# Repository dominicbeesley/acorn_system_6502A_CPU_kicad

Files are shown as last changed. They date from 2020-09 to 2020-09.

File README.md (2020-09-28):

# acorn_system_6502A_CPU_kicad
 Acorn System 6502A clone card

 This is a clone of the Acorn 6502A 1/2/3 MHz card for the System Microcomputer range.

 It is not a perfect copy:
 - some routing (especially on the front copper plane) is not a perfect copy
 - some "extra wiggles" on the Acorn card have not been copied
 - some fixes have been added (see below)

It is intended that as it stands this is a drop-in replacement for the original card. If the fix jumpers are left alone then it should function identically.

# Fixes

Two extra decoupling capacitors and some extra routing has been added. C10 is added close to the CPU. Another C11 is close to IC12, for this to be effective an extra wire may need to be added on the underside of the board to connect VCC direct to the capacitor. It is not clear whether either of these are necessary but some pictures show an extra capacitor tacked onto IC12.

## CPU card always to Generate data stobes

On the original card the NRDS and NWDS data strobe signals are not always generated by the CPU card but are set to tri-state when the bus is granted to another card. This would require any DMA card to contains identical circuitry to the CPU card. An optional link LKD1 can be cut and re-made to have the CPU card always generate these signals.

## Data buffer direction on bus grant

There is seemingly a bug in the original card in that the direction is not reversed when the bus is granted and local (to the CPU card) resources are being accessed by another bus master. (The buffer enable signal _is_ however correctly reversed)

LKD2 if broken and remade will enable the buffer direction to be reversed. This should allow local resources (ROM, 6116, VIA) to be accessed by alternative bus masters.

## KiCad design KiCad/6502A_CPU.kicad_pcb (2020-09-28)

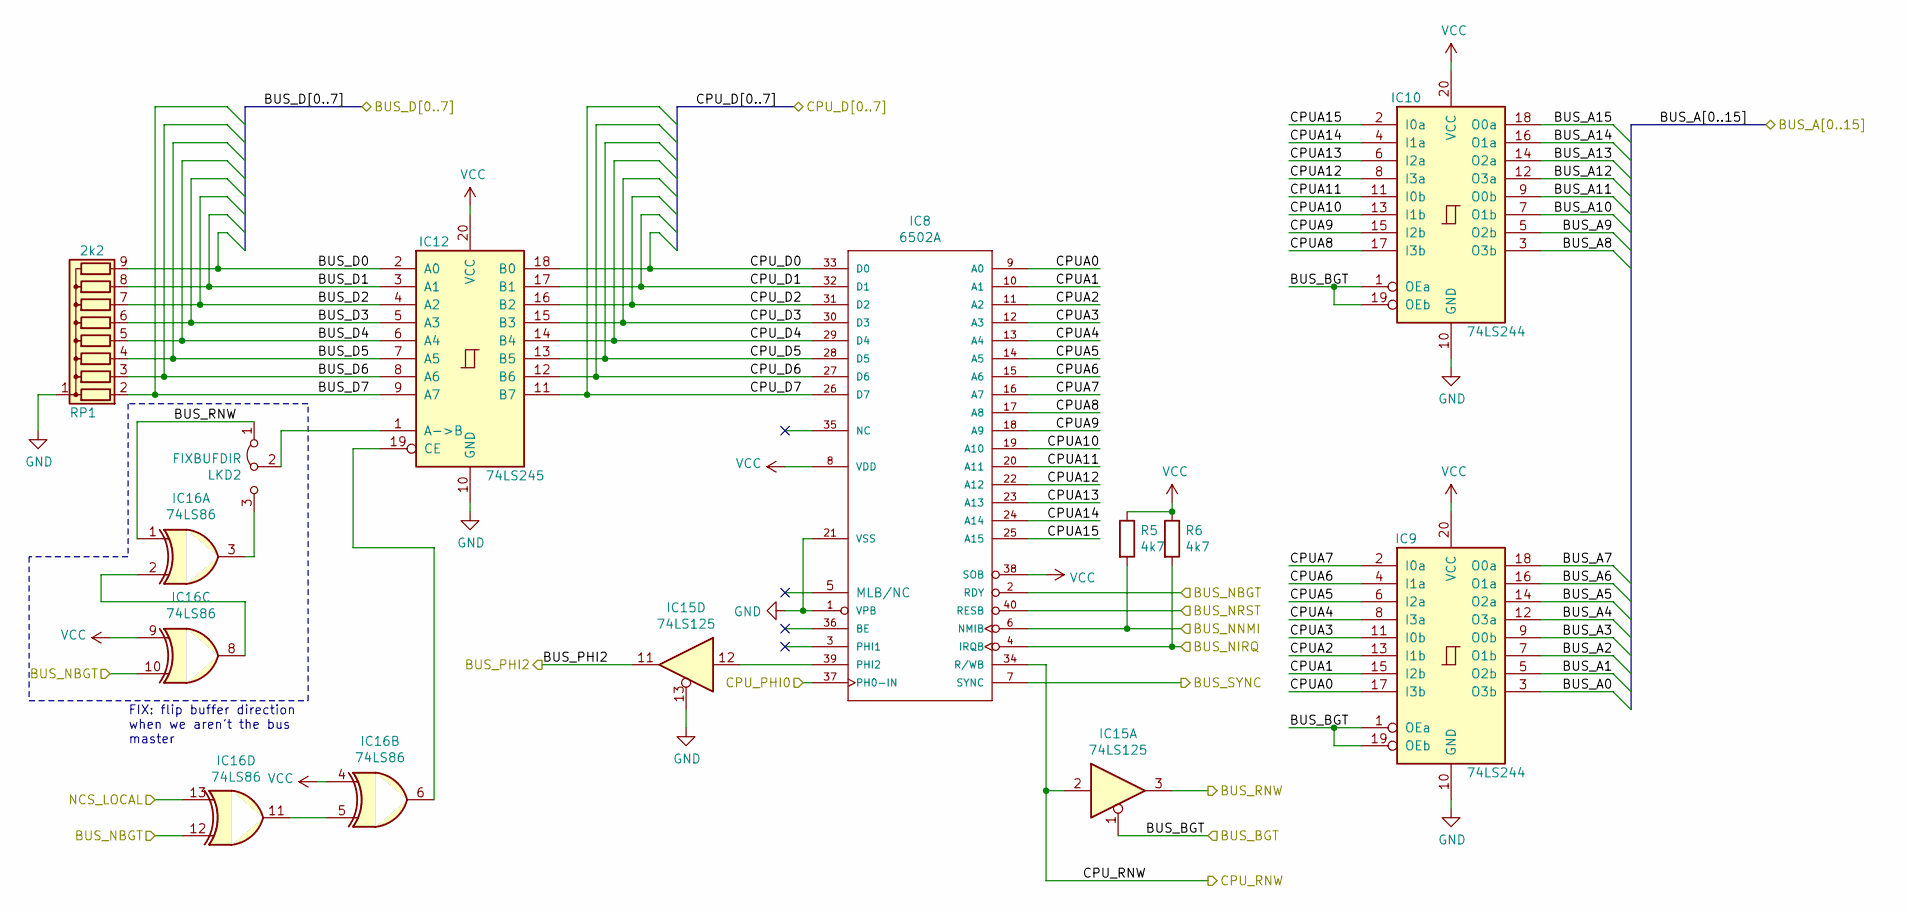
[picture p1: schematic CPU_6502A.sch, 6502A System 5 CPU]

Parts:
IC8: 6502A; DIP-40_W15.24mm_Socket
IC9, IC10: 74LS244; DIP-20_W7.62mm_Socket
IC12: 74LS245; DIP-20_W7.62mm_Socket
IC15: 74LS125; DIP-14_W7.62mm_Socket
IC16: 74LS86; DIP-14_W7.62mm_Socket
LKD2: FIXBUFDIR; Pin_Header_Straight_1x03_Pitch2.54mm_tight_NC12
R5, R6: 4k7; R_Axial_DIN0309_L9.0mm_D2.0mm_P12.70mm_Horizontal
RP1: 2k2; R_Array_SIP9

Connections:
/BUS_NBGT: IC8.2 (RDY), IC16.10, IC16.12; also elsewhere on the board
/BUS_NIRQ: IC8.4 (IRQB), R6.2; also elsewhere on the board
/BUS_NNMI: IC8.6 (NMIB), R5.2; also elsewhere on the board
/BUS_NRST: IC8.40 (RESB); also elsewhere on the board
/BUS_PHI2: IC15.11; also elsewhere on the board
/BUS_RNW: IC15.3, IC16.1, LKD2.1 (A); also elsewhere on the board
/BUS_SYNC: IC8.7 (SYNC); also elsewhere on the board
/CPU_6502A/BUS_A0: IC9.3 (O3b); also elsewhere on the board
/CPU_6502A/BUS_A1: IC9.5 (O2b); also elsewhere on the board
/CPU_6502A/BUS_A2: IC9.7 (O1b); also elsewhere on the board
/CPU_6502A/BUS_A3: IC9.9 (O0b); also elsewhere on the board
/CPU_6502A/BUS_A4: IC9.12 (O3a); also elsewhere on the board
/CPU_6502A/BUS_A5: IC9.14 (O2a); also elsewhere on the board
/CPU_6502A/BUS_A6: IC9.16 (O1a); also elsewhere on the board
/CPU_6502A/BUS_A7: IC9.18 (O0a); also elsewhere on the board
/CPU_6502A/BUS_A8: IC10.3 (O3b); also elsewhere on the board
/CPU_6502A/BUS_A9: IC10.5 (O2b); also elsewhere on the board
/CPU_6502A/BUS_A10: IC10.7 (O1b); also elsewhere on the board
/CPU_6502A/BUS_A11: IC10.9 (O0b); also elsewhere on the board
/CPU_6502A/BUS_A12: IC10.12 (O3a); also elsewhere on the board
/CPU_6502A/BUS_A13: IC10.14 (O2a); also elsewhere on the board
/CPU_6502A/BUS_A14: IC10.16 (O1a); also elsewhere on the board
/CPU_6502A/BUS_A15: IC10.18 (O0a); also elsewhere on the board
/CPU_6502A/BUS_BGT: IC9.1 (OEa), IC9.19 (OEb), IC10.1 (OEa), IC10.19 (OEb), IC15.1; also elsewhere on the board
/CPU_6502A/BUS_D0: IC12.2 (A0), RP1.9 (R8); also elsewhere on the board
/CPU_6502A/BUS_D1: IC12.3 (A1), RP1.8 (R7); also elsewhere on the board
/CPU_6502A/BUS_D2: IC12.4 (A2), RP1.7 (R6); also elsewhere on the board
/CPU_6502A/BUS_D3: IC12.5 (A3), RP1.6 (R5); also elsewhere on the board
/CPU_6502A/BUS_D4: IC12.6 (A4), RP1.5 (R4); also elsewhere on the board
/CPU_6502A/BUS_D5: IC12.7 (A5), RP1.4 (R3); also elsewhere on the board
/CPU_6502A/BUS_D6: IC12.8 (A6), RP1.3 (R2); also elsewhere on the board
/CPU_6502A/BUS_D7: IC12.9 (A7), RP1.2 (R1); also elsewhere on the board
/CPU_6502A/CPUA0: IC8.9 (A0), IC9.17 (I3b)
/CPU_6502A/CPUA1: IC8.10 (A1), IC9.15 (I2b)
/CPU_6502A/CPUA2: IC8.11 (A2), IC9.13 (I1b)
/CPU_6502A/CPUA3: IC8.12 (A3), IC9.11 (I0b)
/CPU_6502A/CPUA4: IC8.13 (A4), IC9.8 (I3a)
/CPU_6502A/CPUA5: IC8.14 (A5), IC9.6 (I2a)
/CPU_6502A/CPUA6: IC8.15 (A6), IC9.4 (I1a)
/CPU_6502A/CPUA7: IC8.16 (A7), IC9.2 (I0a)
/CPU_6502A/CPUA8: IC8.17 (A8), IC10.17 (I3b)
/CPU_6502A/CPUA9: IC8.18 (A9), IC10.15 (I2b)
/CPU_6502A/CPUA10: IC8.19 (A10), IC10.13 (I1b)
/CPU_6502A/CPUA11: IC8.20 (A11), IC10.11 (I0b)
/CPU_6502A/CPUA12: IC8.22 (A12), IC10.8 (I3a)
/CPU_6502A/CPUA13: IC8.23 (A13), IC10.6 (I2a)
/CPU_6502A/CPUA14: IC8.24 (A14), IC10.4 (I1a)
/CPU_6502A/CPUA15: IC8.25 (A15), IC10.2 (I0a)
/CPU_6502A/CPU_D0: IC8.33 (D0), IC12.18 (B0); also elsewhere on the board
/CPU_6502A/CPU_D1: IC8.32 (D1), IC12.17 (B1); also elsewhere on the board
/CPU_6502A/CPU_D2: IC8.31 (D2), IC12.16 (B2); also elsewhere on the board
/CPU_6502A/CPU_D3: IC8.30 (D3), IC12.15 (B3); also elsewhere on the board
/CPU_6502A/CPU_D4: IC8.29 (D4), IC12.14 (B4); also elsewhere on the board
/CPU_6502A/CPU_D5: IC8.28 (D5), IC12.13 (B5); also elsewhere on the board
/CPU_6502A/CPU_D6: IC8.27 (D6), IC12.12 (B6); also elsewhere on the board
/CPU_6502A/CPU_D7: IC8.26 (D7), IC12.11 (B7); also elsewhere on the board
/CPU_6502A/CPU_RNW: IC8.34 (R/WB), IC15.2; also elsewhere on the board
/CPU_6502A/NCS_LOCAL: IC16.13; also elsewhere on the board
/CPU_READY/CPU_CLK_PHI0: IC8.37 (PH0-IN); also elsewhere on the board
GND: IC8.1 (VPB), IC8.21 (VSS), IC9.10 (GND), IC10.10 (GND), IC12.10 (GND), IC15.13, RP1.1 (common); also elsewhere on the board
unnamed: IC12.1 (A->B), LKD2.2 (C)
unnamed: IC12.19 (CE), IC16.6
unnamed: IC8.39 (PHI2), IC15.12
unnamed: IC16.2, IC16.8
unnamed: IC16.3, LKD2.3 (B)
unnamed: IC16.5, IC16.11
VCC: IC8.8 (VDD), IC8.38 (SOB), IC9.20 (VCC), IC10.20 (VCC), IC12.20 (VCC), IC16.4, IC16.9, R5.1, R6.1; also elsewhere on the board

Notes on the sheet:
FIX: flip buffer direction when we aren't the bus master

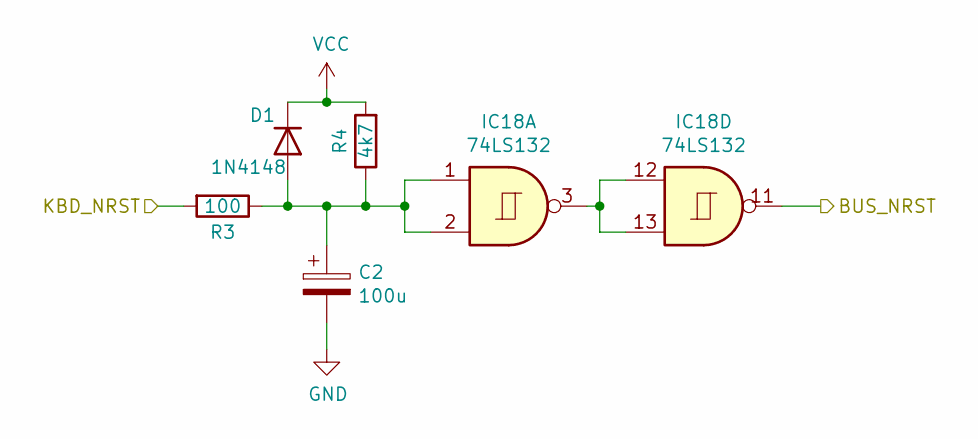
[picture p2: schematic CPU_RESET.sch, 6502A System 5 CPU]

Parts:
C2: 100u; C_Disc_D5.1mm_W3.2mm_P5.00mm
D1: 1N4148; D_DO-35_SOD27_P7.62mm_Horizontal
IC18: 74LS132; DIP-14_W7.62mm_Socket
R3: 100; R_Axial_DIN0309_L9.0mm_D2.0mm_P12.70mm_Horizontal
R4: 4k7; R_Axial_DIN0309_L9.0mm_D2.0mm_P12.70mm_Horizontal

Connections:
/BUS_NRST: IC18.11; also elsewhere on the board
/CPU_RESET/KBD_NRST: R3.2; also elsewhere on the board
GND: C2.2; also elsewhere on the board
unnamed: C2.1, D1.2 (A), IC18.1, IC18.2, R3.1, R4.1
unnamed: IC18.3, IC18.12, IC18.13
VCC: D1.1 (K), R4.2; also elsewhere on the board

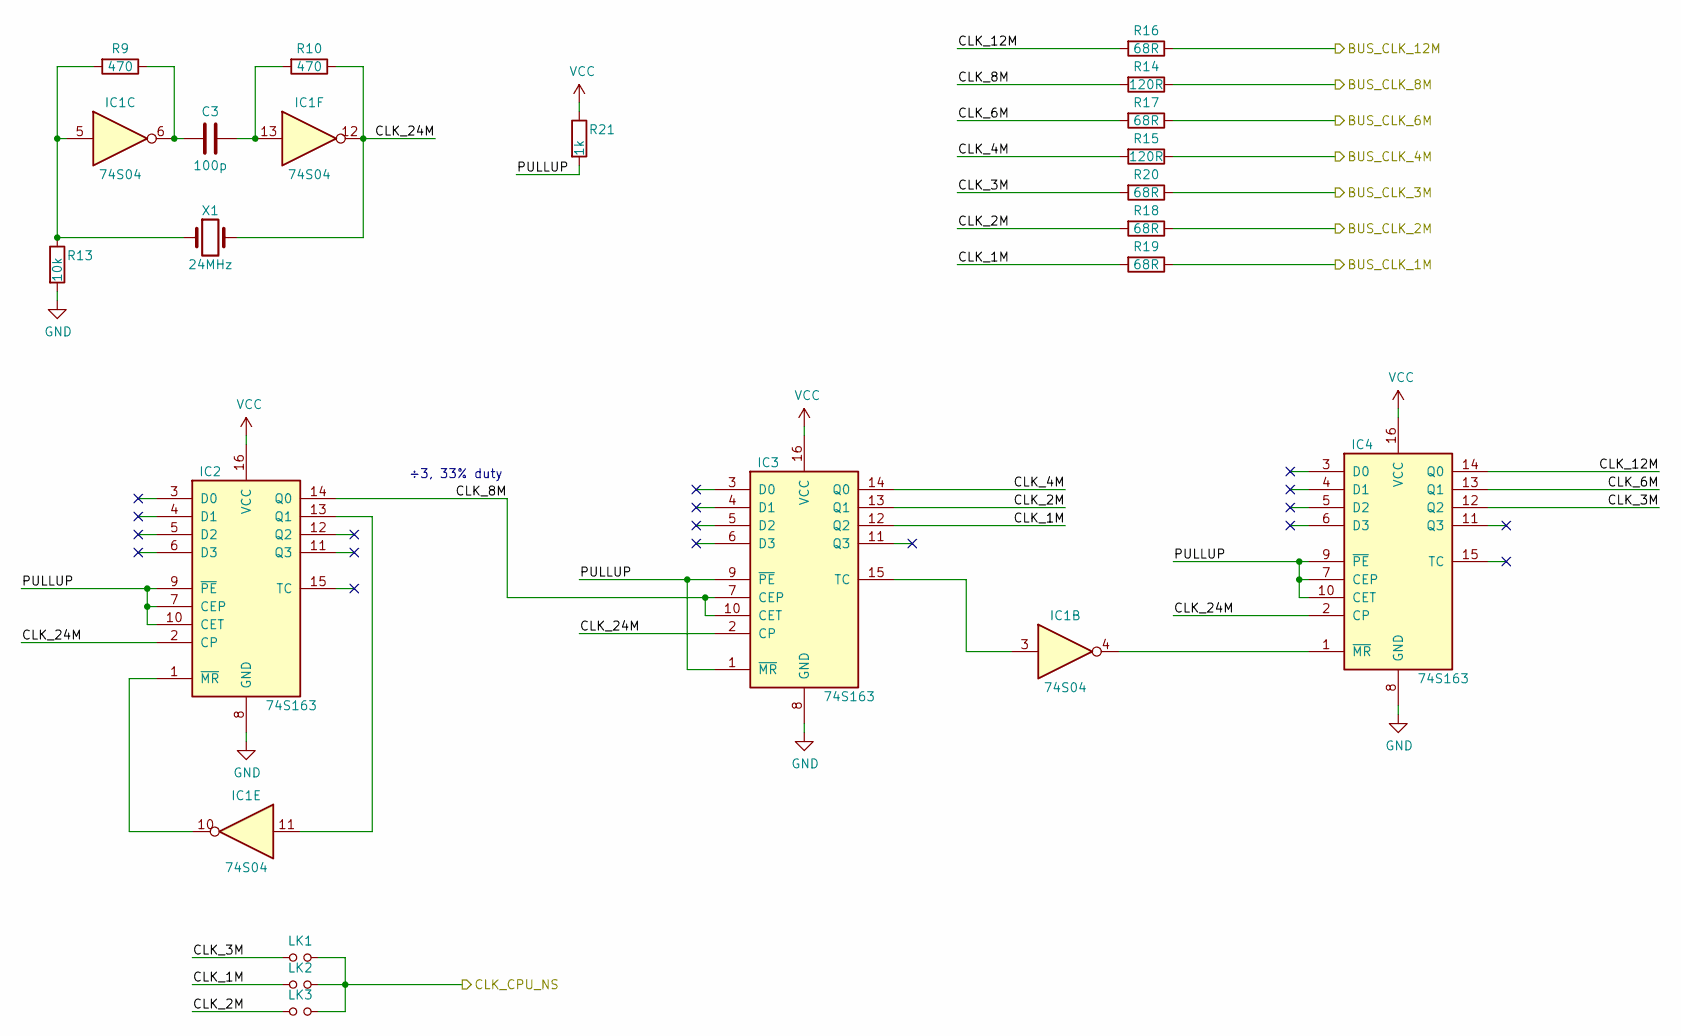
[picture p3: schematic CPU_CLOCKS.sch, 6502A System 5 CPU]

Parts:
C3: 100p; C_Disc_D5.0mm_W2.5mm_P2.50mm
IC1: 74S04; DIP-14_W7.62mm_Socket
IC2, IC3, IC4: 74S163; DIP-16_W7.62mm_Socket
LK1, LK2, LK3: Jumper_NO_Small; Pin_Header_Straight_1x02_Pitch2.54mm-tight
R9: 470; R_Axial_DIN0207_L6.3mm_D2.5mm_P2.54mm_Vertical
R10: 470; R_Axial_DIN0309_L9.0mm_D2.0mm_P12.70mm_Horizontal
R13: 10k; R_Axial_DIN0309_L9.0mm_D2.0mm_P12.70mm_Horizontal
R14, R15: 120R; R_Axial_DIN0207_L6.3mm_D2.5mm_P2.54mm_Vertical
R16, R17, R18, R19, R20: 68R; R_Axial_DIN0207_L6.3mm_D2.5mm_P2.54mm_Vertical
R21: 1k; R_Axial_DIN0309_L9.0mm_D2.0mm_P12.70mm_Horizontal
X1: 24MHz; Resonator-2pin_w8.0mm_h3.5mm

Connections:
/BUS_CLK_1M: R19.1; also elsewhere on the board
/BUS_CLK_2M: R18.1; also elsewhere on the board
/BUS_CLK_3M: R20.1; also elsewhere on the board
/BUS_CLK_4M: R15.1; also elsewhere on the board
/BUS_CLK_6M: R17.1; also elsewhere on the board
/BUS_CLK_8M: R14.1; also elsewhere on the board
/BUS_CLK_12M: R16.1; also elsewhere on the board
/CPU_CLOCKS/CLK_1M: IC3.12 (Q2), LK2.1, R19.2
/CPU_CLOCKS/CLK_2M: IC3.13 (Q1), LK3.1, R18.2
/CPU_CLOCKS/CLK_3M: IC4.12 (Q2), LK1.1, R20.2
/CPU_CLOCKS/CLK_4M: IC3.14 (Q0), R15.2
/CPU_CLOCKS/CLK_6M: IC4.13 (Q1), R17.2
/CPU_CLOCKS/CLK_8M: IC2.14 (Q0), IC3.7 (CEP), IC3.10 (CET), R14.2
/CPU_CLOCKS/CLK_12M: IC4.14 (Q0), R16.2
/CPU_CLOCKS/CLK_24M: IC1.12, IC2.2 (CP), IC3.2 (CP), IC4.2 (CP), R10.1, X1.2
/CPU_CLOCKS/CLK_CPU_NS: LK1.2, LK2.2, LK3.2; also elsewhere on the board
/CPU_CLOCKS/PULLUP: IC2.7 (CEP), IC2.9 (~PE), IC2.10 (CET), IC3.1 (~MR), IC3.9 (~PE), IC4.7 (CEP), IC4.9 (~PE), IC4.10 (CET), R21.2
GND: IC2.8 (GND), IC3.8 (GND), IC4.8 (GND), R13.2; also elsewhere on the board
unnamed: C3.1, IC1.13, R10.2
unnamed: C3.2, IC1.6, R9.1
unnamed: IC1.3, IC3.15 (TC)
unnamed: IC1.4, IC4.1 (~MR)
unnamed: IC1.5, R9.2, R13.1, X1.1
unnamed: IC1.10, IC2.1 (~MR)
unnamed: IC1.11, IC2.13 (Q1)
VCC: IC2.16 (VCC), IC3.16 (VCC), IC4.16 (VCC), R21.1; also elsewhere on the board

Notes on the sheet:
÷3, 33% duty

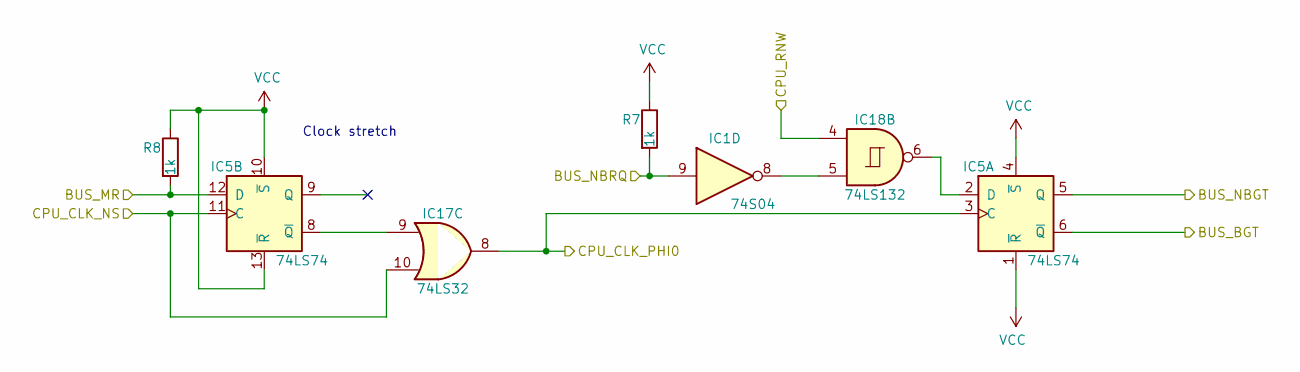
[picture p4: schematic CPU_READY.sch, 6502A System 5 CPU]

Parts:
IC1: 74S04; DIP-14_W7.62mm_Socket
IC5: 74LS74; DIP-14_W7.62mm_Socket
IC17: 74LS32; DIP-14_W7.62mm_Socket
IC18: 74LS132; DIP-14_W7.62mm_Socket
R7, R8: 1k; R_Axial_DIN0309_L9.0mm_D2.0mm_P12.70mm_Horizontal

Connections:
/BUS_MR: IC5.12 (D), R8.2; also elsewhere on the board
/BUS_NBGT: IC5.5 (Q); also elsewhere on the board
/BUS_NBRQ: IC1.9, R7.2; also elsewhere on the board
/CPU_6502A/BUS_BGT: IC5.6 (~Q); also elsewhere on the board
/CPU_6502A/CPU_RNW: IC18.4; also elsewhere on the board
/CPU_CLOCKS/CLK_CPU_NS: IC5.11 (C), IC17.10; also elsewhere on the board
/CPU_READY/CPU_CLK_PHI0: IC5.3 (C), IC17.8; also elsewhere on the board
unnamed: IC1.8, IC18.5
unnamed: IC5.8 (~Q), IC17.9
unnamed: IC5.2 (D), IC18.6
VCC: IC5.1 (~R), IC5.4 (~S), IC5.10 (~S), IC5.13 (~R), R7.1, R8.1; also elsewhere on the board

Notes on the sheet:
Clock stretch

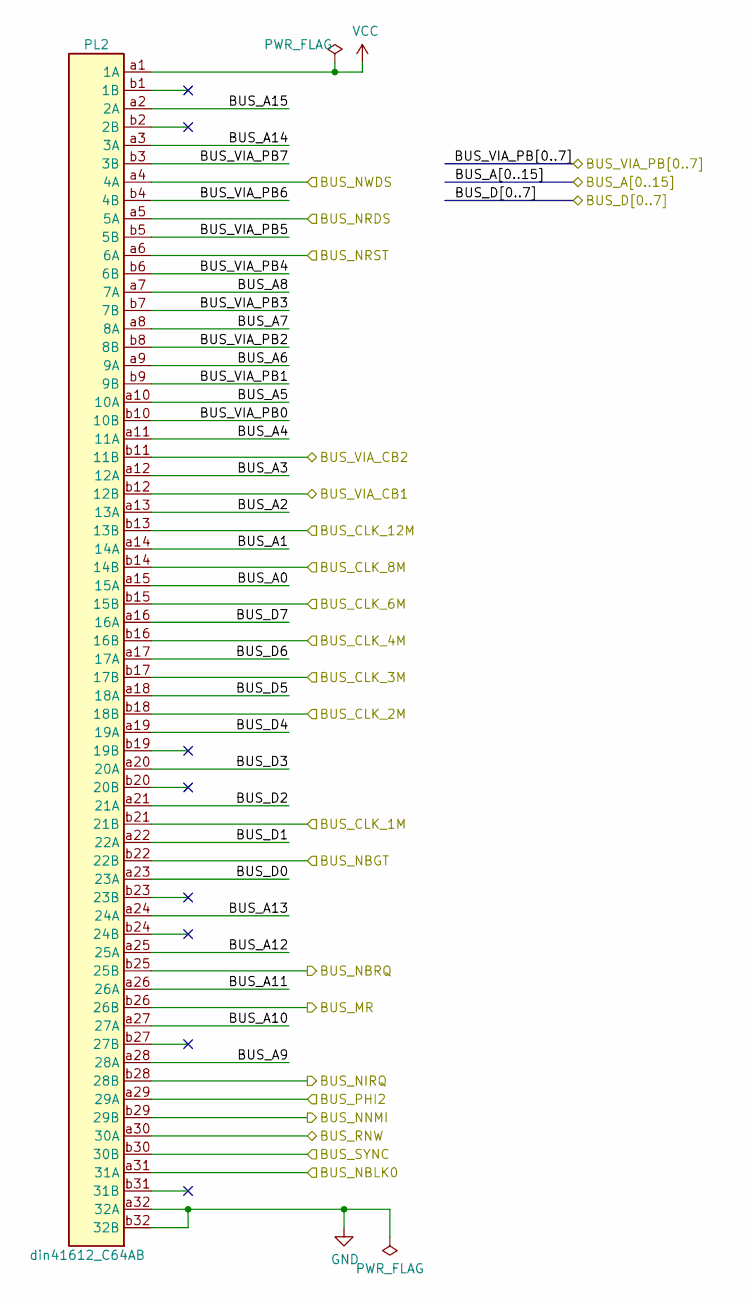
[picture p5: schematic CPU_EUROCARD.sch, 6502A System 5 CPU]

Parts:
PL2: din41612_C64AB; DIN41612_B_2x32_Male_Horizontal_THT

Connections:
/BUS_CLK_1M: PL2.b21 (21B); also elsewhere on the board
/BUS_CLK_2M: PL2.b18 (18B); also elsewhere on the board
/BUS_CLK_3M: PL2.b17 (17B); also elsewhere on the board
/BUS_CLK_4M: PL2.b16 (16B); also elsewhere on the board
/BUS_CLK_6M: PL2.b15 (15B); also elsewhere on the board
/BUS_CLK_8M: PL2.b14 (14B); also elsewhere on the board
/BUS_CLK_12M: PL2.b13 (13B); also elsewhere on the board
/BUS_MR: PL2.b26 (26B); also elsewhere on the board
/BUS_NBGT: PL2.b22 (22B); also elsewhere on the board
/BUS_NBLK0: PL2.a31 (31A); also elsewhere on the board
/BUS_NBRQ: PL2.b25 (25B); also elsewhere on the board
/BUS_NIRQ: PL2.b28 (28B); also elsewhere on the board
/BUS_NNMI: PL2.b29 (29B); also elsewhere on the board
/BUS_NRDS: PL2.a5 (5A); also elsewhere on the board
/BUS_NRST: PL2.a6 (6A); also elsewhere on the board
/BUS_NWDS: PL2.a4 (4A); also elsewhere on the board
/BUS_PHI2: PL2.a29 (29A); also elsewhere on the board
/BUS_RNW: PL2.a30 (30A); also elsewhere on the board
/BUS_SYNC: PL2.b30 (30B); also elsewhere on the board
/BUS_VIA_CB1: PL2.b12 (12B); also elsewhere on the board
/BUS_VIA_CB2: PL2.b11 (11B); also elsewhere on the board
/CPU_6502A/BUS_A0: PL2.a15 (15A); also elsewhere on the board
/CPU_6502A/BUS_A1: PL2.a14 (14A); also elsewhere on the board
/CPU_6502A/BUS_A2: PL2.a13 (13A); also elsewhere on the board
/CPU_6502A/BUS_A3: PL2.a12 (12A); also elsewhere on the board
/CPU_6502A/BUS_A4: PL2.a11 (11A); also elsewhere on the board
/CPU_6502A/BUS_A5: PL2.a10 (10A); also elsewhere on the board
/CPU_6502A/BUS_A6: PL2.a9 (9A); also elsewhere on the board
/CPU_6502A/BUS_A7: PL2.a8 (8A); also elsewhere on the board
/CPU_6502A/BUS_A8: PL2.a7 (7A); also elsewhere on the board
/CPU_6502A/BUS_A9: PL2.a28 (28A); also elsewhere on the board
/CPU_6502A/BUS_A10: PL2.a27 (27A); also elsewhere on the board
/CPU_6502A/BUS_A11: PL2.a26 (26A); also elsewhere on the board
/CPU_6502A/BUS_A12: PL2.a25 (25A); also elsewhere on the board
/CPU_6502A/BUS_A13: PL2.a24 (24A); also elsewhere on the board
/CPU_6502A/BUS_A14: PL2.a3 (3A); also elsewhere on the board
/CPU_6502A/BUS_A15: PL2.a2 (2A); also elsewhere on the board
/CPU_6502A/BUS_D0: PL2.a23 (23A); also elsewhere on the board
/CPU_6502A/BUS_D1: PL2.a22 (22A); also elsewhere on the board
/CPU_6502A/BUS_D2: PL2.a21 (21A); also elsewhere on the board
/CPU_6502A/BUS_D3: PL2.a20 (20A); also elsewhere on the board
/CPU_6502A/BUS_D4: PL2.a19 (19A); also elsewhere on the board
/CPU_6502A/BUS_D5: PL2.a18 (18A); also elsewhere on the board
/CPU_6502A/BUS_D6: PL2.a17 (17A); also elsewhere on the board
/CPU_6502A/BUS_D7: PL2.a16 (16A); also elsewhere on the board
/CPU_EUROCARD/BUS_VIA_PB0: PL2.b10 (10B); also elsewhere on the board
/CPU_EUROCARD/BUS_VIA_PB1: PL2.b9 (9B); also elsewhere on the board
/CPU_EUROCARD/BUS_VIA_PB2: PL2.b8 (8B); also elsewhere on the board
/CPU_EUROCARD/BUS_VIA_PB3: PL2.b7 (7B); also elsewhere on the board
/CPU_EUROCARD/BUS_VIA_PB4: PL2.b6 (6B); also elsewhere on the board
/CPU_EUROCARD/BUS_VIA_PB5: PL2.b5 (5B); also elsewhere on the board
/CPU_EUROCARD/BUS_VIA_PB6: PL2.b4 (4B); also elsewhere on the board
/CPU_EUROCARD/BUS_VIA_PB7: PL2.b3 (3B); also elsewhere on the board
GND: PL2.a32 (32A), PL2.b32 (32B); also elsewhere on the board
VCC: PL2.a1 (1A); also elsewhere on the board

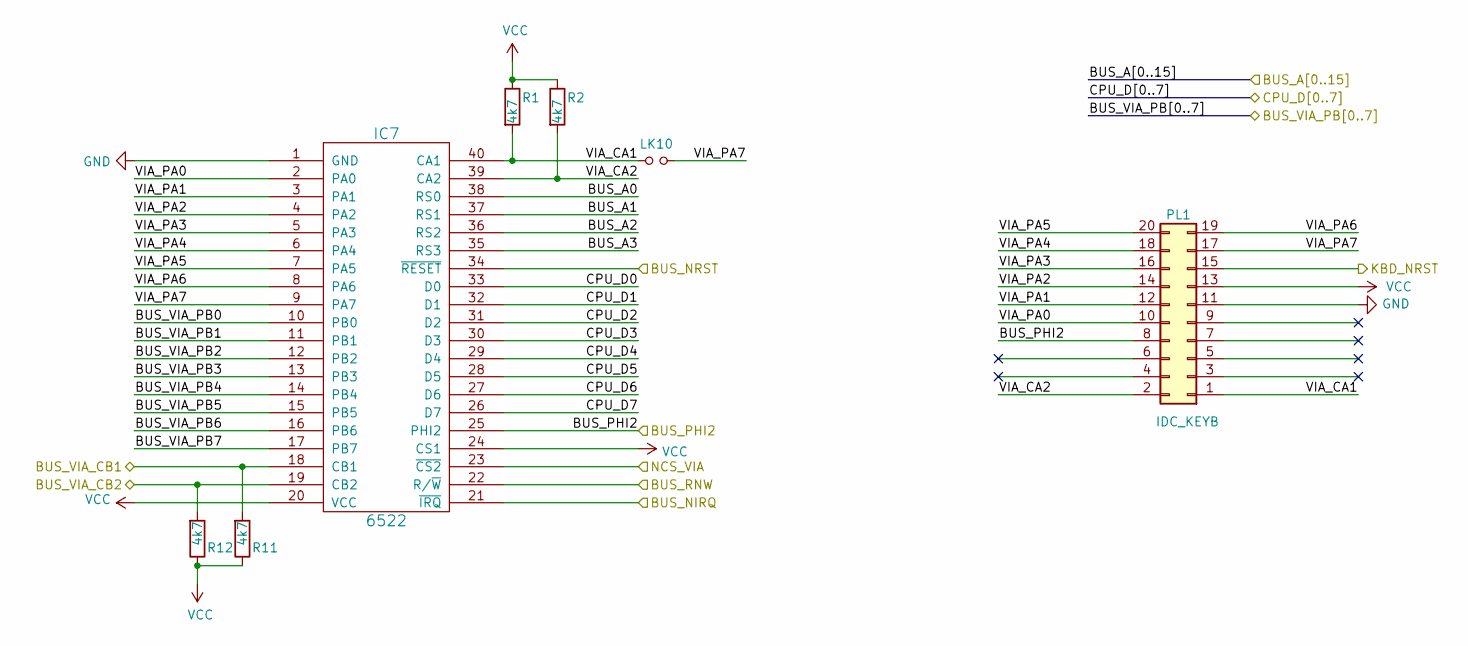
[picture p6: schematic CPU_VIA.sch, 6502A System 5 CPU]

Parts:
IC7: 6522; DIP-40_W15.24mm_Socket
LK10: Jumper_NO_Small; Pin_Header_Straight_1x02_Pitch2.54mm-tight
PL1: IDC_KEYB; IDC-Header_2x10_P2.54mm_Horizontal_Lock_noholes
R1, R2, R11, R12: 4k7; R_Axial_DIN0309_L9.0mm_D2.0mm_P12.70mm_Horizontal

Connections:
/BUS_NIRQ: IC7.21 (~IRQ); also elsewhere on the board
/BUS_NRST: IC7.34 (~RESET); also elsewhere on the board
/BUS_PHI2: IC7.25 (PHI2), PL1.8; also elsewhere on the board
/BUS_RNW: IC7.22 (R/~W); also elsewhere on the board
/BUS_VIA_CB1: IC7.18 (CB1), R11.2; also elsewhere on the board
/BUS_VIA_CB2: IC7.19 (CB2), R12.2; also elsewhere on the board
/CPU_6502A/BUS_A0: IC7.38 (RS0); also elsewhere on the board
/CPU_6502A/BUS_A1: IC7.37 (RS1); also elsewhere on the board
/CPU_6502A/BUS_A2: IC7.36 (RS2); also elsewhere on the board
/CPU_6502A/BUS_A3: IC7.35 (RS3); also elsewhere on the board
/CPU_6502A/CPU_D0: IC7.33 (D0); also elsewhere on the board
/CPU_6502A/CPU_D1: IC7.32 (D1); also elsewhere on the board
/CPU_6502A/CPU_D2: IC7.31 (D2); also elsewhere on the board
/CPU_6502A/CPU_D3: IC7.30 (D3); also elsewhere on the board
/CPU_6502A/CPU_D4: IC7.29 (D4); also elsewhere on the board
/CPU_6502A/CPU_D5: IC7.28 (D5); also elsewhere on the board
/CPU_6502A/CPU_D6: IC7.27 (D6); also elsewhere on the board
/CPU_6502A/CPU_D7: IC7.26 (D7); also elsewhere on the board
/CPU_DEVSEL/NCS_VIA: IC7.23 (~CS2); also elsewhere on the board
/CPU_EUROCARD/BUS_VIA_PB0: IC7.10 (PB0); also elsewhere on the board
/CPU_EUROCARD/BUS_VIA_PB1: IC7.11 (PB1); also elsewhere on the board
/CPU_EUROCARD/BUS_VIA_PB2: IC7.12 (PB2); also elsewhere on the board
/CPU_EUROCARD/BUS_VIA_PB3: IC7.13 (PB3); also elsewhere on the board
/CPU_EUROCARD/BUS_VIA_PB4: IC7.14 (PB4); also elsewhere on the board
/CPU_EUROCARD/BUS_VIA_PB5: IC7.15 (PB5); also elsewhere on the board
/CPU_EUROCARD/BUS_VIA_PB6: IC7.16 (PB6); also elsewhere on the board
/CPU_EUROCARD/BUS_VIA_PB7: IC7.17 (PB7); also elsewhere on the board
/CPU_RESET/KBD_NRST: PL1.15; also elsewhere on the board
/CPU_VIA/VIA_CA1: IC7.40 (CA1), LK10.1, PL1.1, R1.2
/CPU_VIA/VIA_CA2: IC7.39 (CA2), PL1.2, R2.2
/CPU_VIA/VIA_PA0: IC7.2 (PA0), PL1.10
/CPU_VIA/VIA_PA1: IC7.3 (PA1), PL1.12
/CPU_VIA/VIA_PA2: IC7.4 (PA2), PL1.14
/CPU_VIA/VIA_PA3: IC7.5 (PA3), PL1.16
/CPU_VIA/VIA_PA4: IC7.6 (PA4), PL1.18
/CPU_VIA/VIA_PA5: IC7.7 (PA5), PL1.20
/CPU_VIA/VIA_PA6: IC7.8 (PA6), PL1.19
/CPU_VIA/VIA_PA7: IC7.9 (PA7), LK10.2, PL1.17
GND: IC7.1 (GND), PL1.11; also elsewhere on the board
VCC: IC7.20 (VCC), IC7.24 (CS1), PL1.13, R1.1, R2.1, R11.1, R12.1; also elsewhere on the board

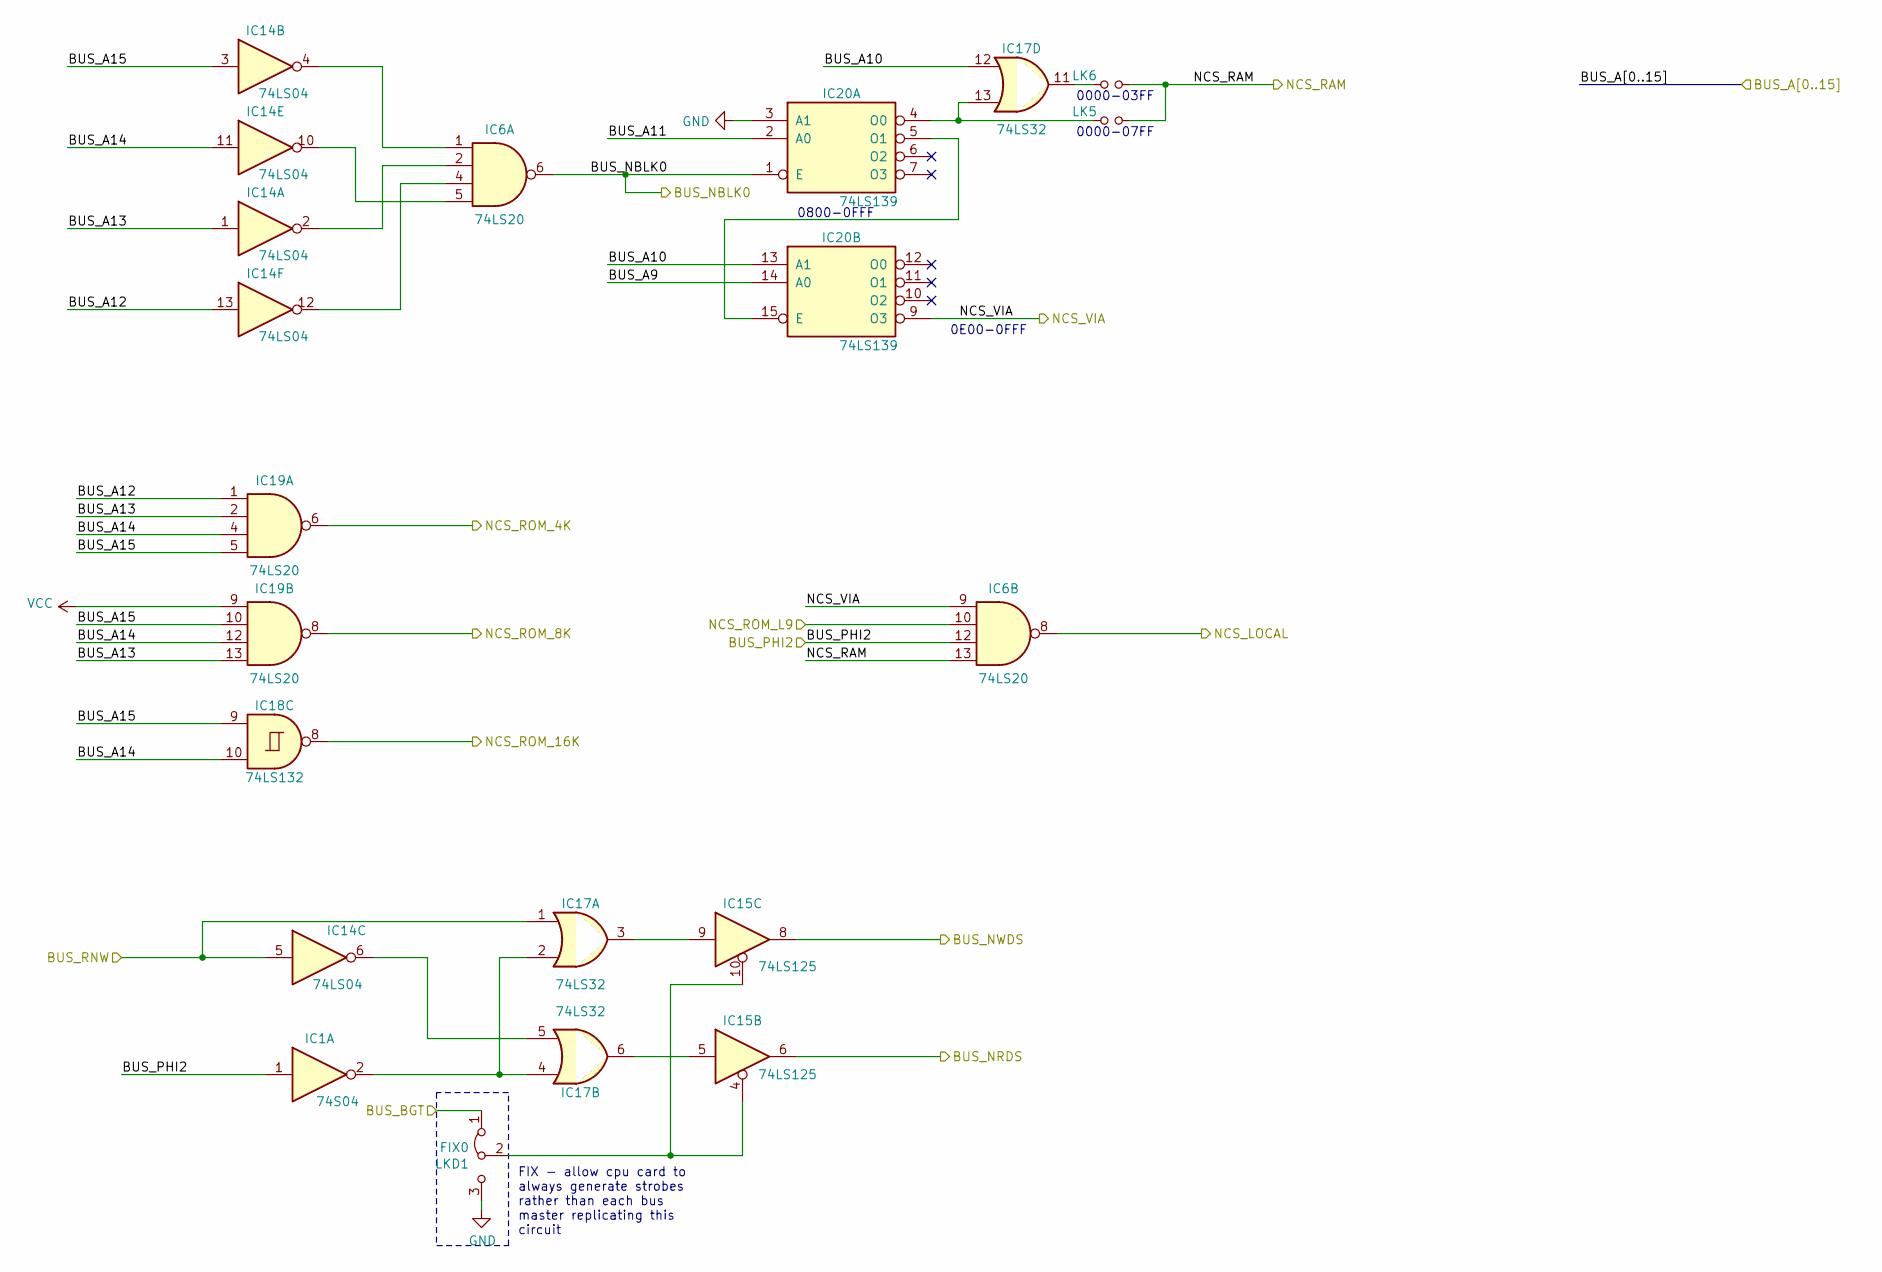
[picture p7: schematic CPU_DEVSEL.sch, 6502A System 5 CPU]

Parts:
IC1: 74S04; DIP-14_W7.62mm_Socket
IC6, IC19: 74LS20; DIP-14_W7.62mm_Socket
IC14: 74LS04; DIP-14_W7.62mm_Socket
IC15: 74LS125; DIP-14_W7.62mm_Socket
IC17: 74LS32; DIP-14_W7.62mm_Socket
IC18: 74LS132; DIP-14_W7.62mm_Socket
IC20: 74LS139; DIP-16_W7.62mm_Socket
LK5, LK6: Jumper_NO_Small; Pin_Header_Straight_1x02_Pitch2.54mm-tight
LKD1: FIX0; Pin_Header_Straight_1x03_Pitch2.54mm_tight_NC12

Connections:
/BUS_NBLK0: IC6.6, IC20.1 (E); also elsewhere on the board
/BUS_NRDS: IC15.6; also elsewhere on the board
/BUS_NWDS: IC15.8; also elsewhere on the board
/BUS_PHI2: IC1.1, IC6.12; also elsewhere on the board
/BUS_RNW: IC14.5, IC17.1; also elsewhere on the board
/CPU_6502A/BUS_A9: IC20.14 (A0); also elsewhere on the board
/CPU_6502A/BUS_A10: IC17.12, IC20.13 (A1); also elsewhere on the board
/CPU_6502A/BUS_A11: IC20.2 (A0); also elsewhere on the board
/CPU_6502A/BUS_A12: IC14.13, IC19.1; also elsewhere on the board
/CPU_6502A/BUS_A13: IC14.1, IC19.2, IC19.13; also elsewhere on the board
/CPU_6502A/BUS_A14: IC14.11, IC18.10, IC19.4, IC19.12; also elsewhere on the board
/CPU_6502A/BUS_A15: IC14.3, IC18.9, IC19.5, IC19.10; also elsewhere on the board
/CPU_6502A/BUS_BGT: LKD1.1 (A); also elsewhere on the board
/CPU_6502A/NCS_LOCAL: IC6.8; also elsewhere on the board
/CPU_DEVSEL/NCS_RAM: IC6.13, LK5.2, LK6.2; also elsewhere on the board
/CPU_DEVSEL/NCS_ROM_4K: IC19.6; also elsewhere on the board
/CPU_DEVSEL/NCS_ROM_8K: IC19.8; also elsewhere on the board
/CPU_DEVSEL/NCS_ROM_16K: IC18.8; also elsewhere on the board
/CPU_DEVSEL/NCS_ROM_L9: IC6.10; also elsewhere on the board
/CPU_DEVSEL/NCS_VIA: IC6.9, IC20.9 (O3); also elsewhere on the board
GND: IC20.3 (A1), LKD1.3 (B); also elsewhere on the board
unnamed: IC1.2, IC17.2, IC17.4
unnamed: IC6.2, IC14.2
unnamed: IC6.1, IC14.4
unnamed: IC14.6, IC17.5
unnamed: IC6.5, IC14.10
unnamed: IC6.4, IC14.12
unnamed: IC15.5, IC17.6
unnamed: IC15.9, IC17.3
unnamed: IC15.4, IC15.10, LKD1.2 (C)
unnamed: IC17.11, LK6.1
unnamed: IC17.13, IC20.4 (O0), LK5.1
unnamed: IC20.5 (O1), IC20.15 (E)
VCC: IC19.9; also elsewhere on the board

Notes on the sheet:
0000-07FF
0000-03FF
0800-0FFF
0E00-0FFF
FIX - allow cpu card to always generate strobes rather than each bus master replicating this circuit

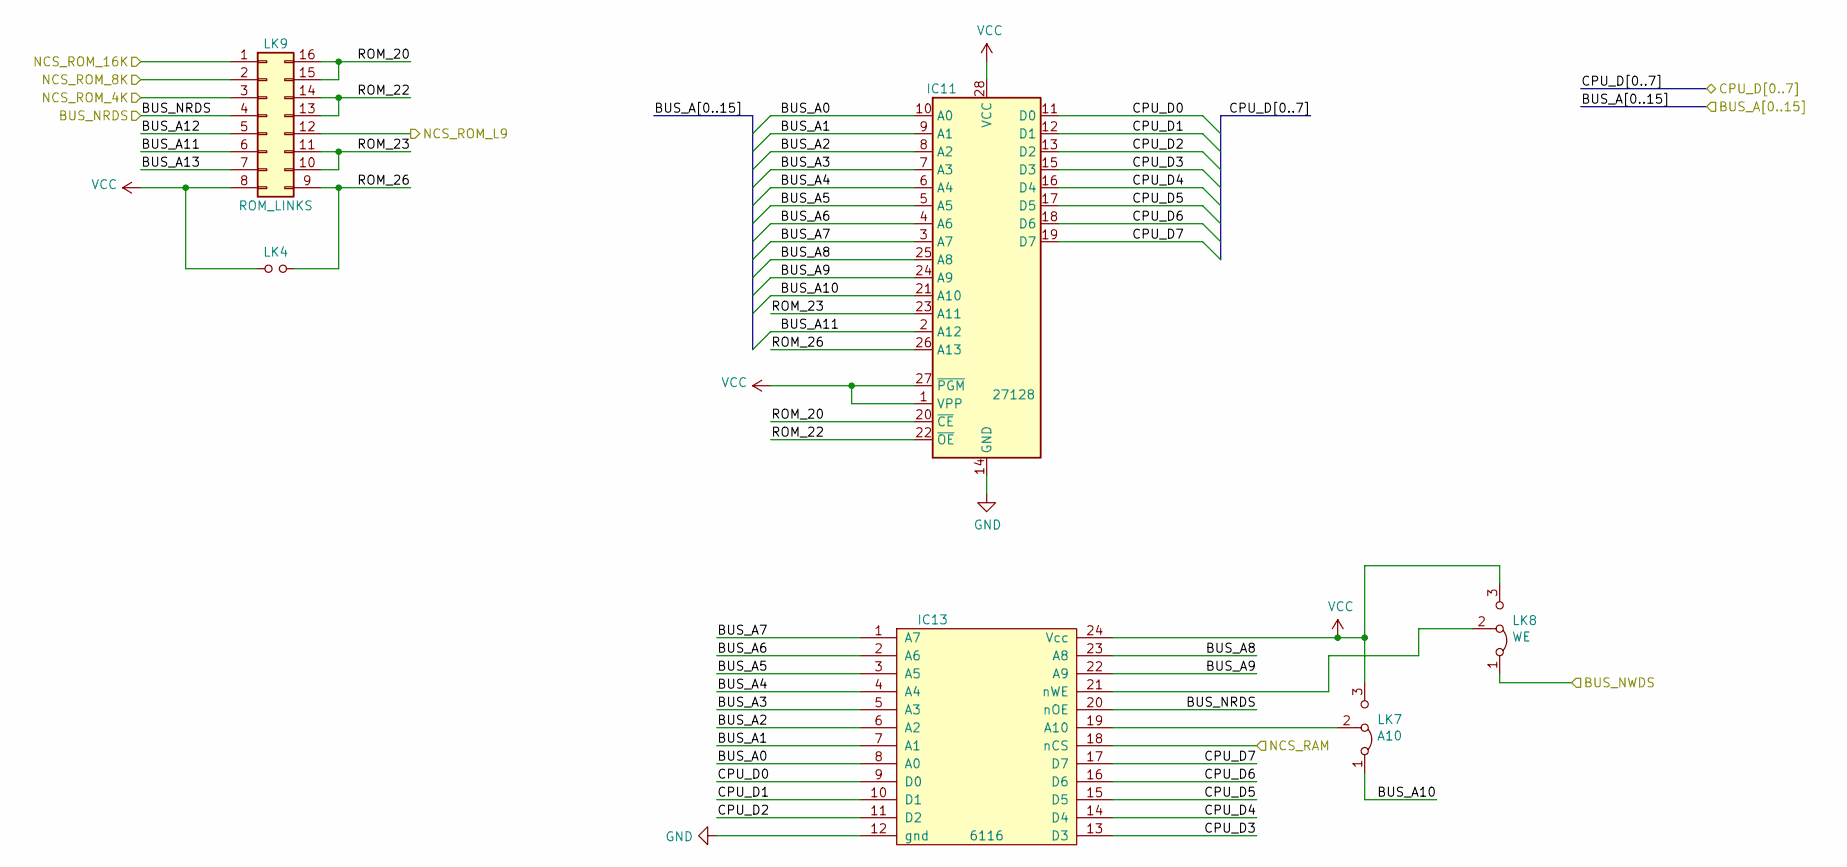
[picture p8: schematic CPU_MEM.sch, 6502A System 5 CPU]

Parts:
IC11: 27128; DIP-28_W15.24mm_Socket
IC13: 6116; DIP-24_W15.24mm
LK4: Jumper_NO_Small; Pin_Header_Straight_1x02_Pitch2.54mm-tight
LK7: A10; Pin_Header_Straight_1x03_Pitch2.54mm_tight_NC12
LK8: WE; Pin_Header_Straight_1x03_Pitch2.54mm_tight_NC12
LK9: ROM_LINKS; DIP-16_W7.62mm_Socket

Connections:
/BUS_NRDS: IC13.20 (nOE), LK9.4; also elsewhere on the board
/BUS_NWDS: LK8.1 (A); also elsewhere on the board
/CPU_6502A/BUS_A0: IC11.10 (A0), IC13.8 (A0); also elsewhere on the board
/CPU_6502A/BUS_A1: IC11.9 (A1), IC13.7 (A1); also elsewhere on the board
/CPU_6502A/BUS_A2: IC11.8 (A2), IC13.6 (A2); also elsewhere on the board
/CPU_6502A/BUS_A3: IC11.7 (A3), IC13.5 (A3); also elsewhere on the board
/CPU_6502A/BUS_A4: IC11.6 (A4), IC13.4 (A4); also elsewhere on the board
/CPU_6502A/BUS_A5: IC11.5 (A5), IC13.3 (A5); also elsewhere on the board
/CPU_6502A/BUS_A6: IC11.4 (A6), IC13.2 (A6); also elsewhere on the board
/CPU_6502A/BUS_A7: IC11.3 (A7), IC13.1 (A7); also elsewhere on the board
/CPU_6502A/BUS_A8: IC11.25 (A8), IC13.23 (A8); also elsewhere on the board
/CPU_6502A/BUS_A9: IC11.24 (A9), IC13.22 (A9); also elsewhere on the board
/CPU_6502A/BUS_A10: IC11.21 (A10), LK7.1 (A); also elsewhere on the board
/CPU_6502A/BUS_A11: IC11.2 (A12), LK9.6; also elsewhere on the board
/CPU_6502A/BUS_A12: LK9.5; also elsewhere on the board
/CPU_6502A/BUS_A13: LK9.7; also elsewhere on the board
/CPU_6502A/CPU_D0: IC11.11 (D0), IC13.9 (D0); also elsewhere on the board
/CPU_6502A/CPU_D1: IC11.12 (D1), IC13.10 (D1); also elsewhere on the board
/CPU_6502A/CPU_D2: IC11.13 (D2), IC13.11 (D2); also elsewhere on the board
/CPU_6502A/CPU_D3: IC11.15 (D3), IC13.13 (D3); also elsewhere on the board
/CPU_6502A/CPU_D4: IC11.16 (D4), IC13.14 (D4); also elsewhere on the board
/CPU_6502A/CPU_D5: IC11.17 (D5), IC13.15 (D5); also elsewhere on the board
/CPU_6502A/CPU_D6: IC11.18 (D6), IC13.16 (D6); also elsewhere on the board
/CPU_6502A/CPU_D7: IC11.19 (D7), IC13.17 (D7); also elsewhere on the board
/CPU_DEVSEL/NCS_RAM: IC13.18 (nCS); also elsewhere on the board
/CPU_DEVSEL/NCS_ROM_4K: LK9.3; also elsewhere on the board
/CPU_DEVSEL/NCS_ROM_8K: LK9.2; also elsewhere on the board
/CPU_DEVSEL/NCS_ROM_16K: LK9.1; also elsewhere on the board
/CPU_DEVSEL/NCS_ROM_L9: LK9.12; also elsewhere on the board
/CPU_MEM/ROM_20: IC11.20 (~CE), LK9.15, LK9.16
/CPU_MEM/ROM_22: IC11.22 (~OE), LK9.13, LK9.14
/CPU_MEM/ROM_23: IC11.23 (A11), LK9.10, LK9.11
/CPU_MEM/ROM_26: IC11.26 (A13), LK4.2, LK9.9
GND: IC11.14 (GND), IC13.12 (gnd); also elsewhere on the board
unnamed: IC13.19 (A10), LK7.2 (C)
unnamed: IC13.21 (nWE), LK8.2 (C)
VCC: IC11.1 (VPP), IC11.27 (~PGM), IC11.28 (VCC), IC13.24 (Vcc), LK4.1, LK7.3 (B), LK8.3 (B), LK9.8; also elsewhere on the board

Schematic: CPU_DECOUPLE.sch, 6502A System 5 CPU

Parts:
C1: 22u; CP_Axial_L10.0mm_D4.5mm_P15.00mm_Horizontal_tight
C4, C5, C6, C7: 47n; C_Disc_D3.0mm_W1.6mm_P2.50mm
C8: 47n; C_Disc_D3.0mm_W1.6mm_P2.50mm_tight
C9, C10, C11: 47n; C_Disc_D3.0mm_W1.6mm_P2.54mm_tight
IC1: 74S04; DIP-14_W7.62mm_Socket
IC5: 74LS74; DIP-14_W7.62mm_Socket
IC6, IC19: 74LS20; DIP-14_W7.62mm_Socket
IC14: 74LS04; DIP-14_W7.62mm_Socket
IC15: 74LS125; DIP-14_W7.62mm_Socket
IC16: 74LS86; DIP-14_W7.62mm_Socket
IC17: 74LS32; DIP-14_W7.62mm_Socket
IC18: 74LS132; DIP-14_W7.62mm_Socket
IC20: 74LS139

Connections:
GND: C1.2, C4.2, C5.2, C6.2, C7.2, C8.2, C9.2, C10.2, C11.2, IC1.7 (GND), IC5.7 (GND), IC6.7 (GND), IC14.7 (GND), IC15.7 (GND), IC16.7 (GND), IC17.7 (GND), IC18.7 (GND), IC19.7 (GND), IC20.8 (GND); also elsewhere on the board
VCC: C1.1, C4.1, C5.1, C6.1, C7.1, C8.1, C9.1, C10.1, C11.1, IC1.14 (VCC), IC5.14 (VCC), IC6.14 (VCC), IC14.14 (VCC), IC15.14 (VCC), IC16.14 (VCC), IC17.14 (VCC), IC18.14 (VCC), IC19.14 (VCC), IC20.16 (VCC); also elsewhere on the board

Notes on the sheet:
FIX: extra decouplers

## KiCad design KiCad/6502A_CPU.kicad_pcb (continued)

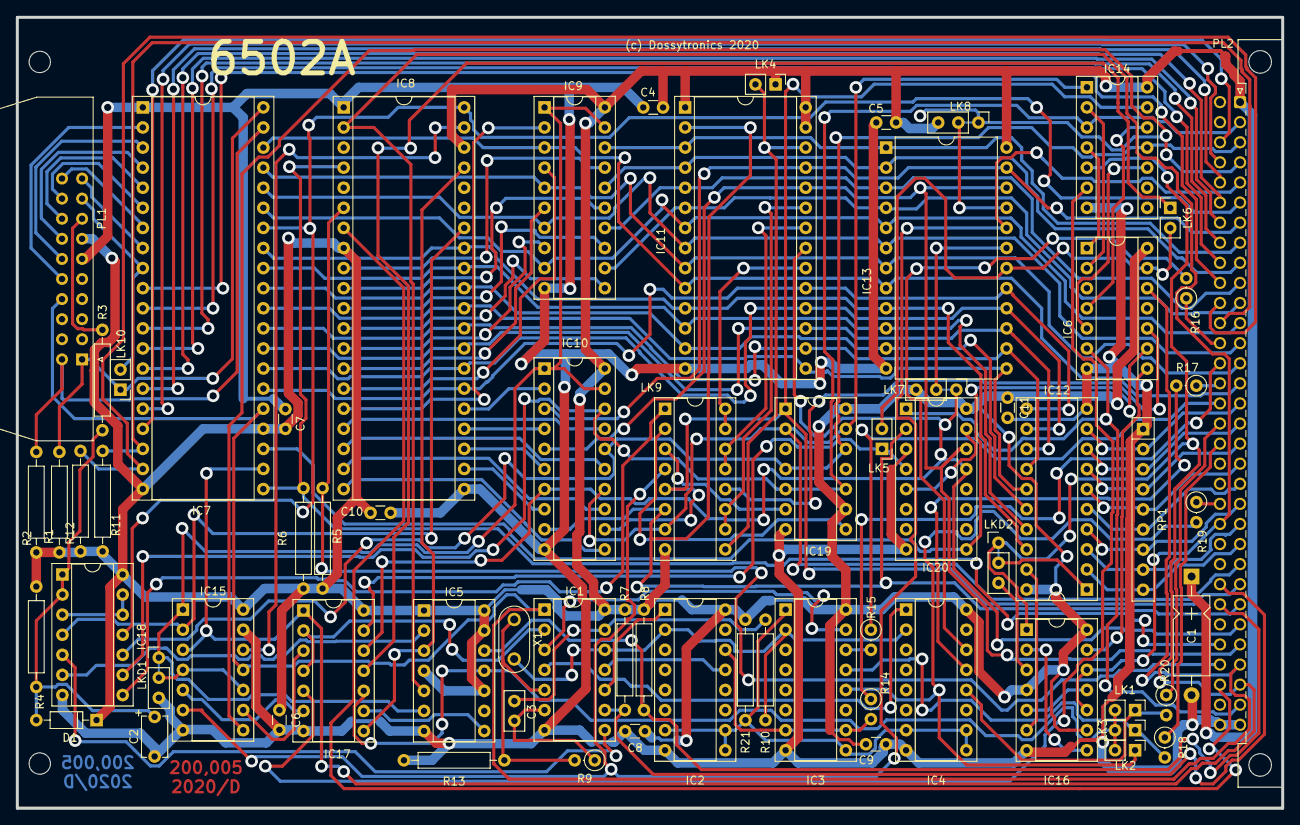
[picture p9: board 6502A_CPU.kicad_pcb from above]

Board: 2 copper layers, 160.0 x 100.0 mm, 69 parts (0 on the bottom side), 146 nets.
